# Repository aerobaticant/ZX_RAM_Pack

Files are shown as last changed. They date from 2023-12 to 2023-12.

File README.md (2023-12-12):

# ZX RAM Pack
This is my design for a RAM pack for the Sinclair ZX81 computer.
<br>It uses a 62256 SRAM IC to give 32KiB of RAM available to BASIC.

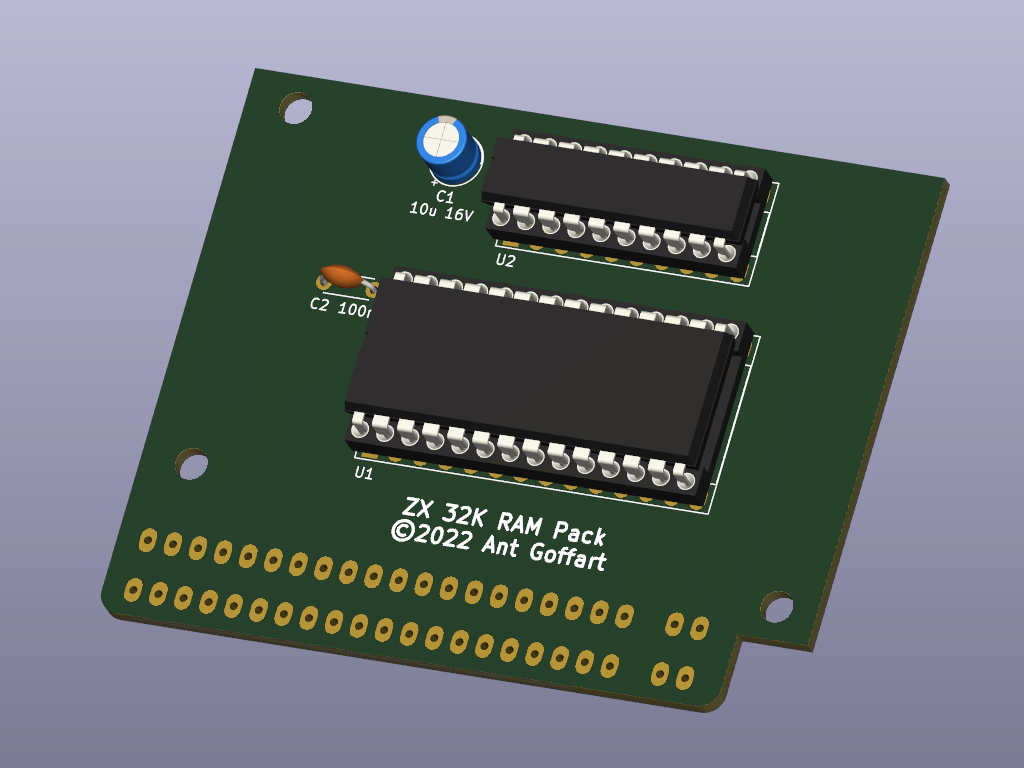
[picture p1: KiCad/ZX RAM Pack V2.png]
<picture></picture>

## PLD
A 16V8 PLD is used to do the address decoding.

RAM is enabled when A13, A14 or A15 are high ($2000-$FFFF)
<br>RAM area $4000-$7FFF is shadowed at $C000-$FFFF

RAM is read during MREQ or RFSH to allow Hi Res Graphics

ROM shadow is disabled when A15 is high ($8000-$BFFF)
<br>Note: ZX80 has no ROMCS signal so ROM shadow can't be disabled
<br>This means the ZX80 can only be given 16K

ROM is also disabled in address $0004 following reset to allow auto detection
<br>Pull-ups on the data bus generate LD BC,$FFFF instead of LD BC,$7FFF for RAM-CHECK

## Schematic
The Schematic and PCB were created in KiCAD

## STLs
I have also created a 3D printable enclosure based on the design of the original ZX80's 3KB RAM pack.
<br>You may have to rotate the parts to suit your 3D printer.

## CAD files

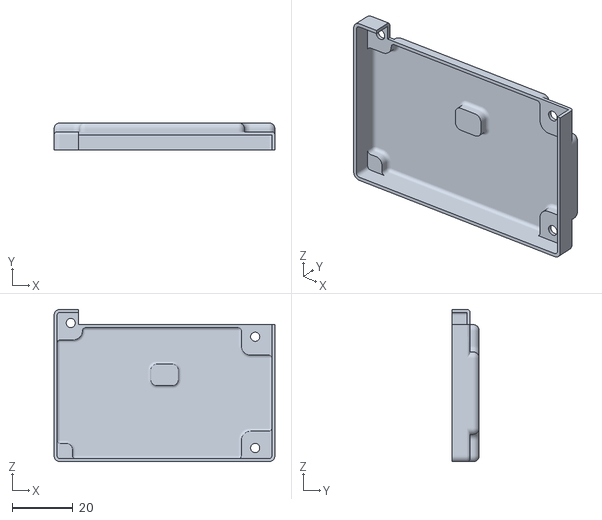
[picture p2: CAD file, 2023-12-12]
ZX_RAM_Pack-Front.stl
72.5 x 9.00 x 50.0

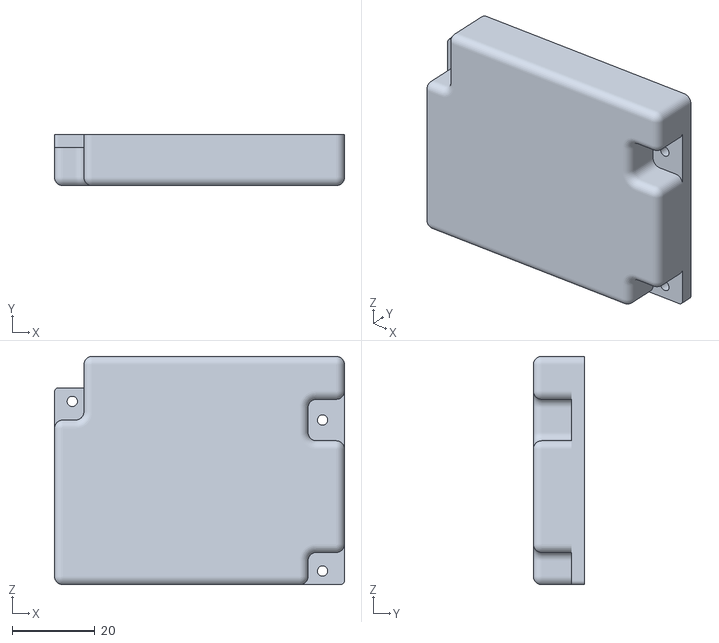
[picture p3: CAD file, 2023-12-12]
ZX_RAM_Pack-Back.stl
70.1 x 12.4 x 55.2

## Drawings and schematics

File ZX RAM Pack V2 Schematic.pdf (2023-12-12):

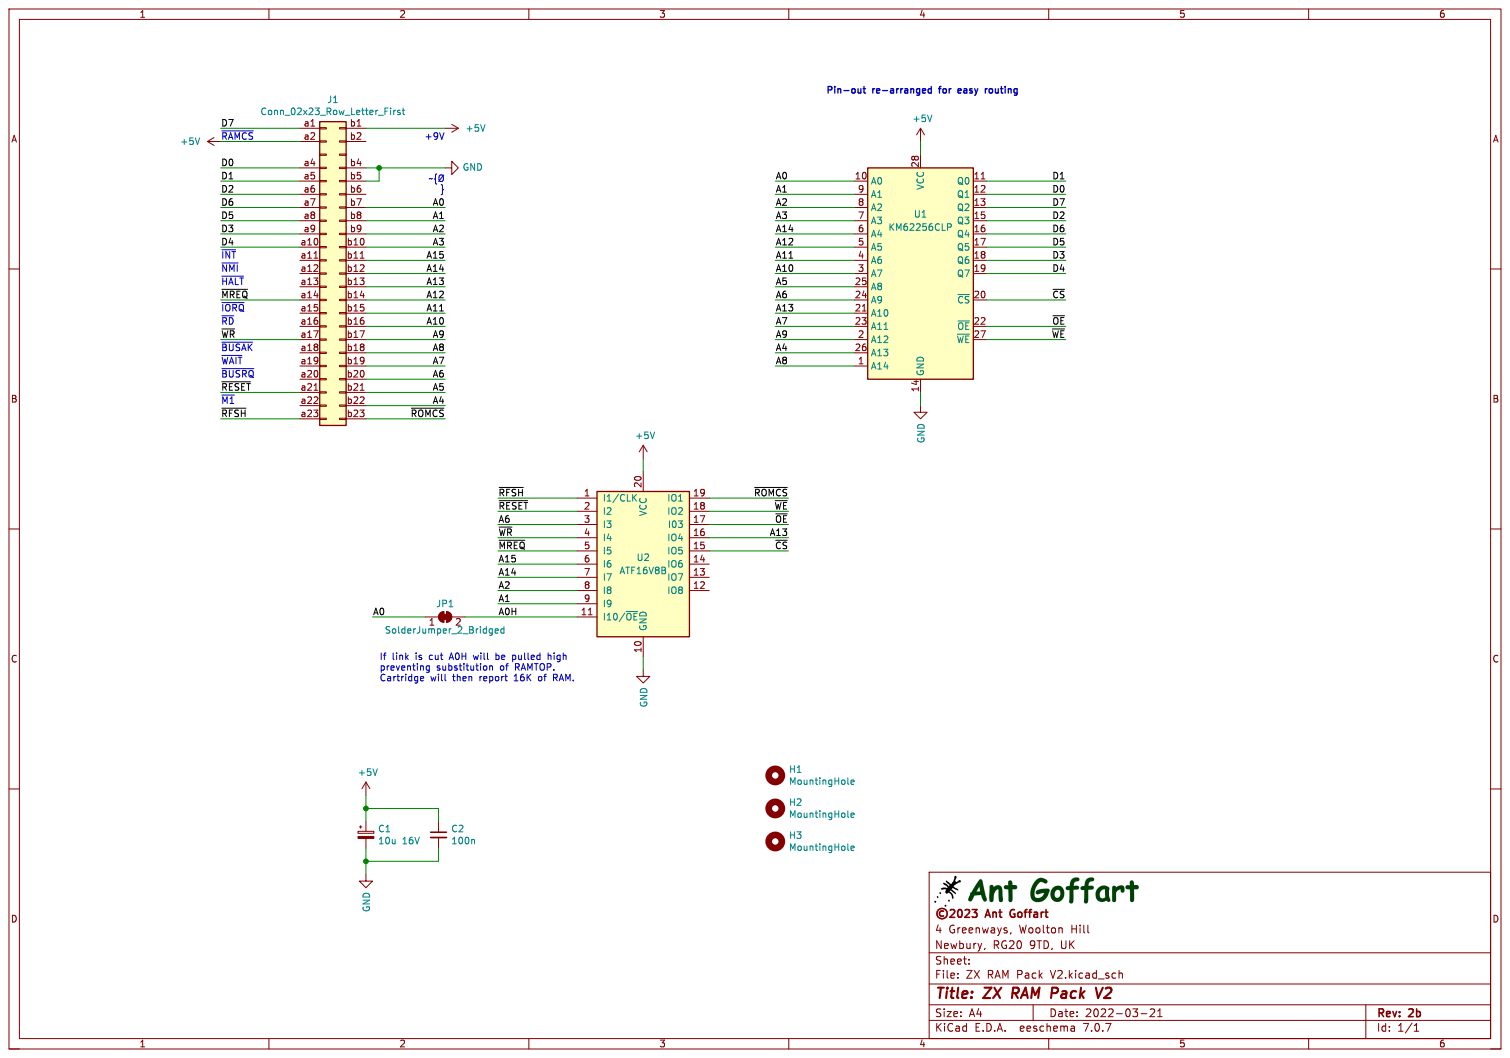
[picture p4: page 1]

If link is cut A0H will be pulled high

Id: 1/1 Title: ZX RAM Pack V2

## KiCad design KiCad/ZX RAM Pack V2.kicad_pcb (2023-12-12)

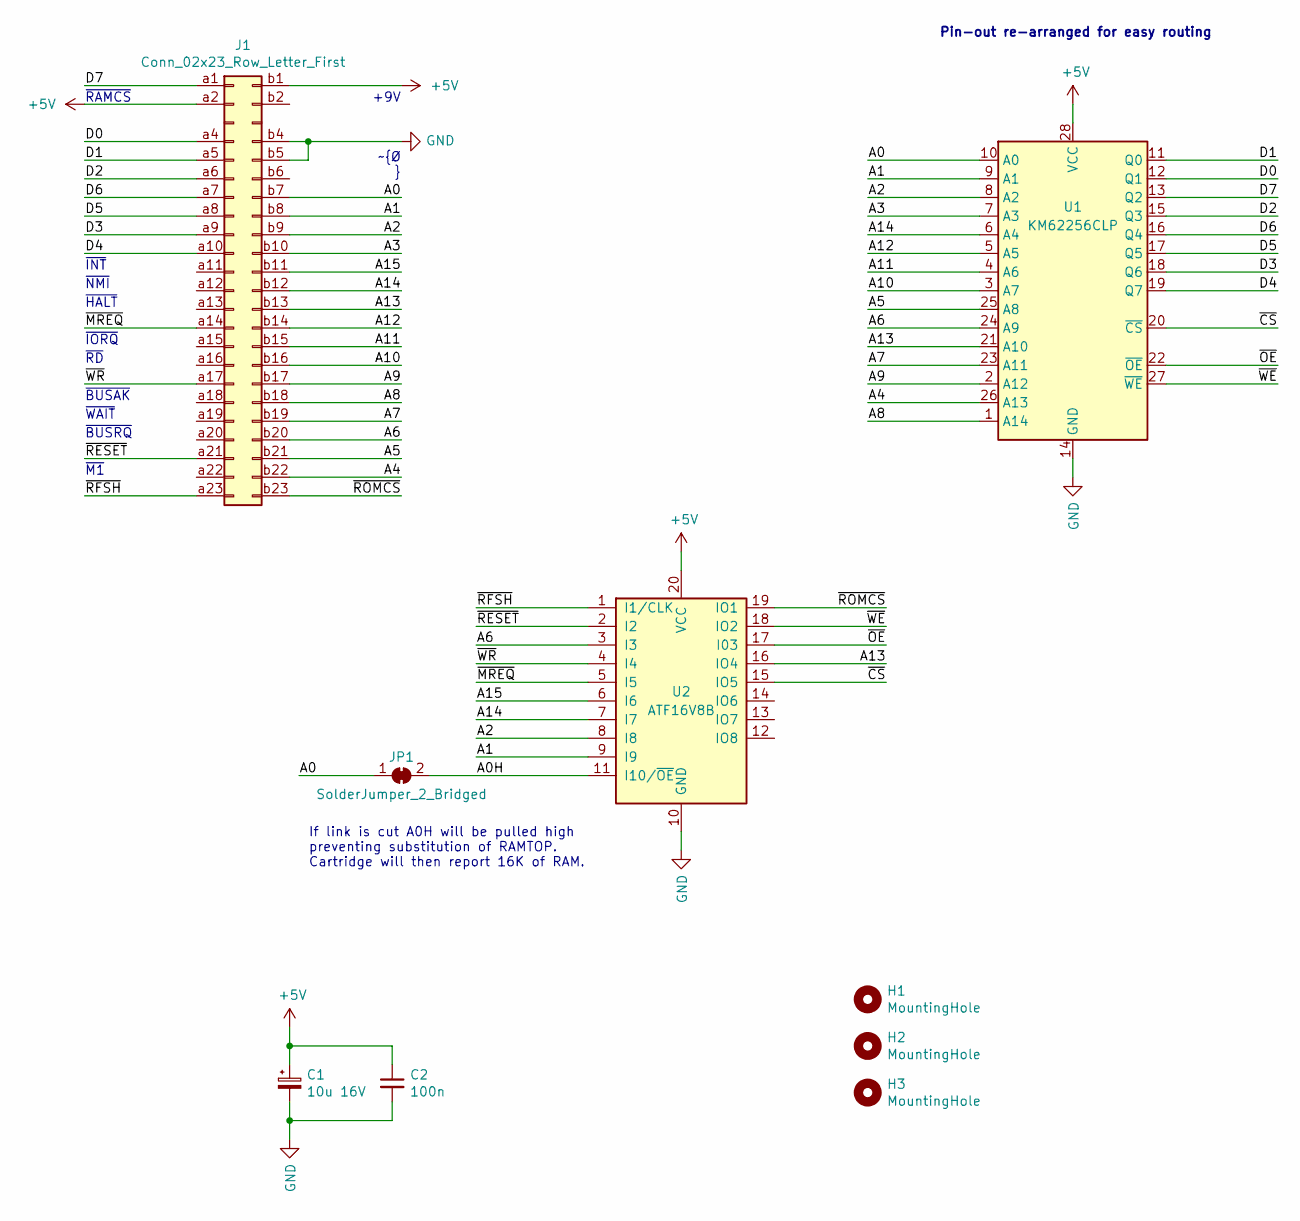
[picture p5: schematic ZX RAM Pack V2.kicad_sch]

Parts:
C1: 10u 16V; CP_Radial_D5.0mm_P2.50mm
C2: 100n; C_Disc_D4.3mm_W1.9mm_P5.00mm
H1, H2, H3: MountingHole; MountingHole_3.2mm_M3
J1: Conn_02x23_Row_Letter_First; Connector_ZX80_ZX80_Card_Edge_2x24
JP1: SolderJumper_2_Bridged; SolderJumper-2_P1.3mm_Bridged_RoundedPad1.0x1.5mm
U1: KM62256CLP; DIP-28_W15.24mm_Socket_LongPads
U2: ATF16V8B; DIP-20_W7.62mm_Socket_LongPads

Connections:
+5V: C1.1, C2.1, J1.a2, J1.b1, U1.28 (VCC), U2.20 (VCC)
/A0: J1.b7, JP1.1 (A), U1.10 (A0)
/A0H: JP1.2 (B), U2.11 (I10/~OE)
/A1: J1.b8, U1.9 (A1), U2.9 (I9)
/A2: J1.b9, U1.8 (A2), U2.8 (I8)
/A3: J1.b10, U1.7 (A3)
/A4: J1.b22, U1.26 (A13)
/A5: J1.b21, U1.25 (A8)
/A6: J1.b20, U1.24 (A9), U2.3 (I3)
/A7: J1.b19, U1.23 (A11)
/A8: J1.b18, U1.1 (A14)
/A9: J1.b17, U1.2 (A12)
/A10: J1.b16, U1.3 (A7)
/A11: J1.b15, U1.4 (A6)
/A12: J1.b14, U1.5 (A5)
/A13: J1.b13, U1.21 (A10), U2.16 (IO4)
/A14: J1.b12, U1.6 (A4), U2.7 (I7)
/A15: J1.b11, U2.6 (I6)
/D0: J1.a4, U1.12 (Q1)
/D1: J1.a5, U1.11 (Q0)
/D2: J1.a6, U1.15 (Q3)
/D3: J1.a9, U1.18 (Q6)
/D4: J1.a10, U1.19 (Q7)
/D5: J1.a8, U1.17 (Q5)
/D6: J1.a7, U1.16 (Q4)
/D7: J1.a1, U1.13 (Q2)
/~CS: U1.20 (~CS), U2.15 (IO5)
/~MREQ: J1.a14, U2.5 (I5)
/~OE: U1.22 (~OE), U2.17 (I03)
/~RESET: J1.a21, U2.2 (I2)
/~RFSH: J1.a23, U2.1 (I1/CLK)
/~ROMCS: J1.b23, U2.19 (IO1)
/~WE: U1.27 (~WE), U2.18 (IO2)
/~WR: J1.a17, U2.4 (I4)
GND: C1.2, C2.2, J1.b4, J1.b5, U1.14 (GND), U2.10 (GND)

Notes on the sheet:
+9V
~{IORQ}
~{INT}
If link is cut A0H will be pulled high preventing substitution of RAMTOP. Cartridge will then report 16K of RAM.
~{BUSRQ}
~{NMI}
Pin-out re-arranged for easy routing
~{RAMCS}
~{WAIT}
~{M1}
~{Ø }
~{HALT}
~{BUSAK}
~{RD}

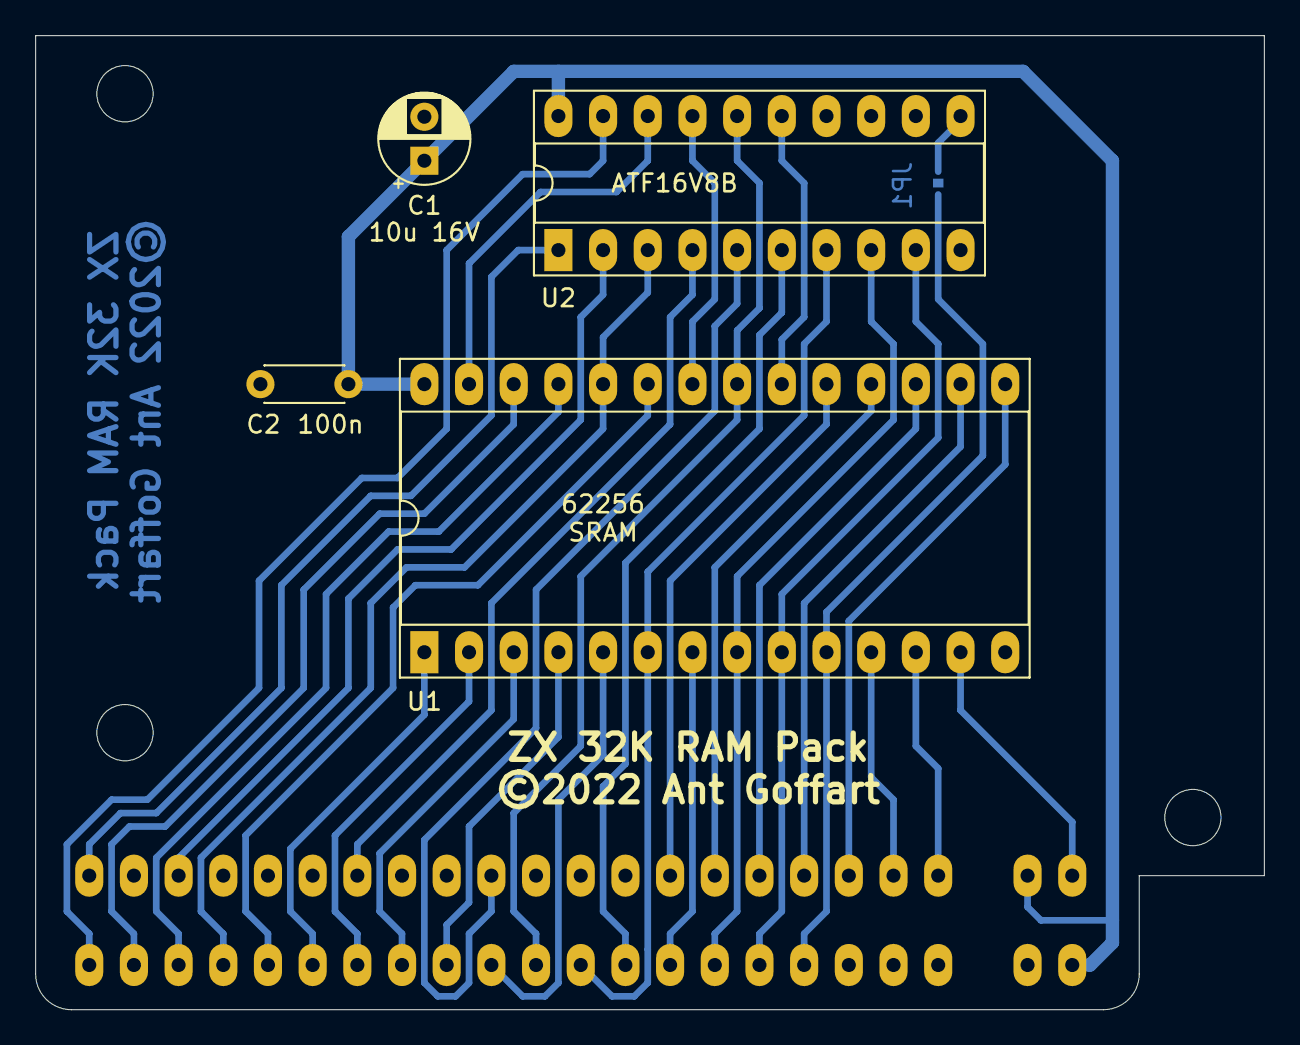
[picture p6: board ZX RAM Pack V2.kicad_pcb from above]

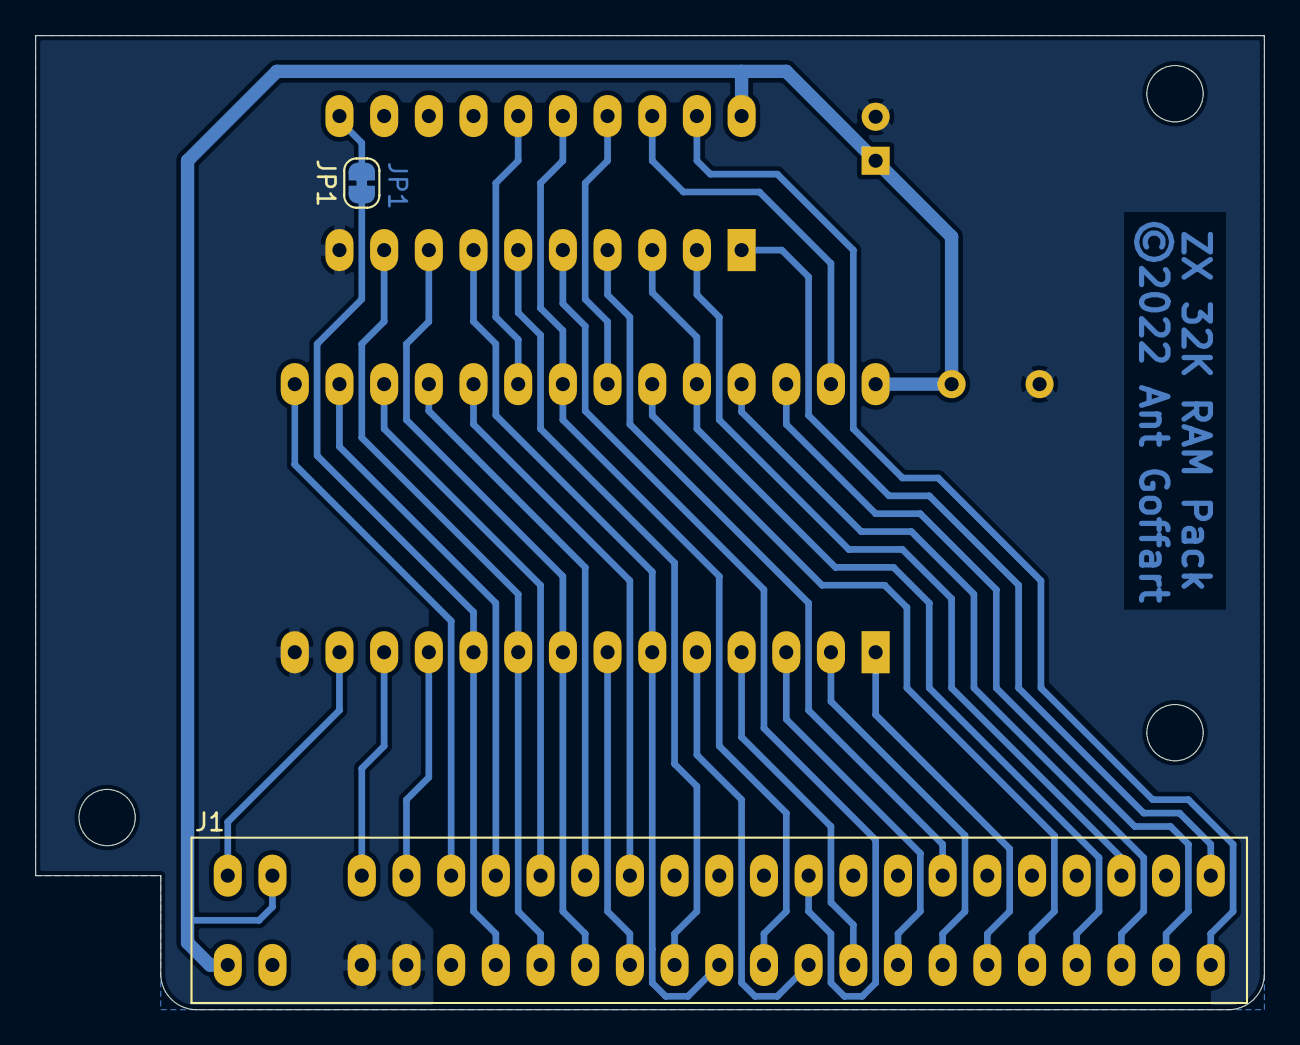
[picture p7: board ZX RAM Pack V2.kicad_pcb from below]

Board: 2 copper layers, 69.8 x 55.4 mm, 9 parts (2 on the bottom side), 35 nets.

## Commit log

2023-12-12 Add initial project files
    [ZX_RAM_Pack-Back.stl, ZX_RAM_Pack-Front.stl]
2023-12-12 Add KiCad Design
    [ZX RAM Pack V2.kicad_pcb, ZX RAM Pack V2.kicad_sch]

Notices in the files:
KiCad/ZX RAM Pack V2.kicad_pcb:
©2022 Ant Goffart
